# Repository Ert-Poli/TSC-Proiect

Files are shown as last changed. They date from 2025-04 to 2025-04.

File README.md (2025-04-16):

Prezentare Generală

OpenBook ESP32-C6 este o platformă hardware portabilă și eficientă energetic, concepută pentru aplicații embedded. Aceasta are la bază microcontrollerul ESP32-C6-WROOM-1-N8, ce oferă suport pentru Wi-Fi 6 și Bluetooth 5.0 Low Energy, precum și o varietate de interfețe pentru conectarea senzorilor și a altor module externe. Sistemul integrează un ecran e-paper, senzor de mediu BME688, ceas în timp real DS3231SN, memorie NOR Flash de 64MB, cititor pentru card microSD și un sistem de alimentare pe bază de baterie LiPo, cu încărcare integrată și monitorizare a nivelului de energie.

Bill of Materials

Componenta	Link	Datasheet
ESP32_WROVER_EAGLE-LTSPICE_RR0402	https://www.snapeda.com/parts/RC0402FR-07226RL/Yageo/view-part/	https://www.snapeda.com/parts/RC0402FR-07226RL/Yageo/datasheet/
QWIIC_CONNECTORJS-1MM	https://www.snapeda.com/parts/PRT-14417/SparkFun/view-part/	https://www.snapeda.com/parts/PRT-14417/SparkFun%20Electronics/datasheet/
BUTTON_CUSYOMV1	https://industry.panasonic.com/global/en/downloads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	https://industry.panasonic.com/global/en/downloads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
ESP32_WROVER_EAGLE-LTSPICE_CC0402	https://componentsearchengine.com/part-view/CC0402MRX5R5BB106/YAGEO	https://componentsearchengine.com/Datasheets/2/CC0402MRX5R5BB106.pdf
CPH3225A	https://www.snapeda.com/parts/CPH3225A/Seiko+Instruments/view-part/?ref=eda	https://www.snapeda.com/parts/CPH3225A/Seiko%20Instruments/datasheet/
ADAFRUIT_LEDCHIP-LED0603	https://www.snapeda.com/parts/KP-1608SURCK/Kingbright/view-part/?ref=search&t=LED%200603	https://www.snapeda.com/parts/KP-1608SURCK/Kingbright/datasheet/
112A-TAAR-R03_ATTEND	https://store.comet.bg/en/Catalogue/Product/43497/	https://store.comet.bg/en/Catalogue/Product/43497/
744043680IND_4828-WE-TPC_WRE	https://www.digikey.sg/en/models/1638515	https://www.we-online.com/components/products/datasheet/744043680.pdf
BD5229G-TR	https://componentsearchengine.com/part-view/BD5229G-TR/ROHM%20Semiconductor	https://datasheet.datasheetarchive.com/originals/distributors/Datasheets_SAMA/f2b9741ef86007909f138d561a359946.pdf
CPH3225A	https://www.snapeda.com/parts/CPH3225A/Seiko+Instruments/view-part/?ref=eda	https://www.snapeda.com/parts/CPH3225A/Seiko%20Instruments/datasheet/
DS3231SN	https://www.snapeda.com/parts/DS3231SN%23/Analog+Devices/view-part/?ref=eda	https://www.snapeda.com/parts/DS3231SN%23/Analog%20Devices/datasheet/
ESP32-C6-WROOM-1-N8	https://www.snapeda.com/parts/ESP32-C6-WROOM-1-N8/Espressif+Systems/view-part/?ref=eda	https://www.snapeda.com/parts/ESP32-C6-WROOM-1-N8/Espressif%20Systems/datasheet/
MCP73831	https://www.digikey.com/en/models/1874108	https://ww1.microchip.com/downloads/aemDocuments/documents/APID/ProductDocuments/DataSheets/MCP73831-Family-Data-Sheet-DS20001984H.pdf
ESP32_WROVER_BME680_BME680	https://www.snapeda.com/parts/BME680/Bosch/view-part/?welcome=home	https://www.snapeda.com/parts/BME680/Bosch%20Sensortec/datasheet/
ESP32_WROVER_EAGLE-LTSPICE_CC0402	https://componentsearchengine.com/Datasheets/2/CC0402MRX5R5BB106.pdf	https://componentsearchengine.com/part-view/CC0402MRX5R5BB106/YAGEO
ESP32_WROVER_SPARKFUN-DISCRETESEMI_MOSFET_PCH-DMG2305UX-7	https://componentsearchengine.com/part-view/DMG2305UX-7/Diodes%20Incorporated	https://www.diodes.com//assets/Datasheets/DMG2305UX.pdf
ESP32C6_VARISTORCN1812	https://www.mouser.co.uk/ProductDetail/EPCOS-TDK/B72520T0350K062?qs=dEfas%2FXlABIszF52uu7vrg%3D%3D	https://www.tdk-electronics.tdk.com/inf/75/db/CTVS_14/Surge_protection_series.pdf
FH34SRJ-24S-0.5SH_99_	https://componentsearchengine.com/part-view/XC6220A331MR-G/Torex	https://product.torexsemi.com/system/files/series/xc6220.pdf
MAX17048G+T10	https://www.snapeda.com/parts/MAX17048G+T10/Analog+Devices/view-part/?ref=eda	https://www.snapeda.com/parts/MAX17048G+T10/Analog%20Devices/datasheet/
MBR0530	https://ro.mouser.com/ProductDetail/KYOCERA-AVX/SD0805S020S1R0?qs=jCA%252BPfw4LHbpkAoSnwrdjw%3D%3D	https://ro.mouser.com/datasheet/2/40/schottky-3165252.pdf
PGB1010603MR	https://www.snapeda.com/parts/PGB1010603MR/Littelfuse/view-part/?ref=eda	https://www.snapeda.com/parts/PGB1010603MR/Littelfuse%20Inc./datasheet/
RCL_CPOL-EUCT3528	https://ro.mouser.com/ProductDetail/Vishay-Sprague/TR3B106K025C1300?qs=jCGqFXxTmLdffnuDkXzk1g%3D%3D	https://www.vishay.com/docs/40080/tr3.pdf
SAMACSYS_PARTS_USB4110-GF-A	https://componentsearchengine.com/part-view/USB4110-GF-A/GCT%20(GLOBAL%20CONNECTOR%20TECHNOLOGY)	https://gct.co/files/drawings/usb4110.pdf
SI1308EDL-T1-GE3	https://componentsearchengine.com/part-view/SI1308EDL-T1-GE3/Vishay	https://componentsearchengine.com/Datasheets/1/SI1308EDL-T1-GE3.pdf
SJ	https://grabcad.com/library/solder-jumpers-1	
USBLC6-2SC6Y	https://www.snapeda.com/parts/USBLC6-2SC6Y/STMicroelectronics/view-part/?ref=eda	https://www.snapeda.com/parts/USBLC6-2SC6Y/STMicroelectronics/datasheet/
W25Q512JVEIQ	https://www.snapeda.com/parts/W25Q512JVEIQ/Winbond+Electronics/view-part/?ref=eda	https://www.snapeda.com/parts/W25Q512JVEIQ/Winbond%20Electronics/datasheet/
XC6220A331MR-G	https://componentsearchengine.com/part-view/XC6220A331MR-G/Torex



Componente Hardware
ESP32-C6
Microcontrollerul ESP32-C6 gestionează întreaga funcționare a sistemului, inclusiv comunicarea cu perifericele, procesarea datelor și optimizarea consumului energetic.
Arhitectură RISC-V pe 32 de biți
Frecvență: până la 160 MHz
Conectivitate: Wi-Fi 6, Bluetooth 5.0
GPIO-uri versatile pentru interfețe I2C, SPI și UART

Modul RTC – DS3231SN
Ceas în timp real cu precizie ridicată și compensare termică
Funcționează independent de sistem, chiar și în mod oprit
I2C partajat cu senzorul de mediu
Senzor BME688
Măsoară temperatura, umiditatea, presiunea și compuși volatili (VOC)
Conectat pe magistrala I2C comună cu RTC
Ideal pentru analiza condițiilor ambientale și optimizarea afișajului

Ecran E-Paper
Tehnologie de afișaj pasivă, cu consum extrem de redus
Controlat prin SPI și pini RST, DC, BUSY
Dimensiune: 7.5"
Rezoluție: 800x480 px

Memorie NOR Flash – 64MB
Model W25Q512JVEIQ
Stocare SPI pentru loguri și grafice e-paper

Slot microSD
Alternativă de stocare pentru volume mari de date
Comunică prin SPI, cu chip select dedicate

Sistem de Alimentare
Intrare USB-C cu protecție ESD
Suportă baterii LiPo de 3.7V, minim 1500mAh
Încărcător: MCP73831
Monitorizare nivel baterie: MAX17048 (I2C)
Stabilizare tensiune: LDO 3.3V

Protecție și Conectivitate
USB-C cu protecție ESD și diodă Schottky pentru polaritate inversă
Asigură atât alimentare cât și transfer de date

Interfață cu Utilizatorul
Butoane tactile pentru controlul funcțiilor
Conector Qwiic pentru extinderea cu senzori I2C
GPIO-uri disponibile pentru alte extensii

Interfețe de Comunicație
SPI – utilizat pentru e-paper, card SD și memoria NOR Flash
I2C – folosit pentru BME688, DS3231SN și MAX17048
UART – debug și programare
GPIO – pentru control general și butoane
Wireless – conectivitate prin Wi-Fi 6 și BLE 5.0

Supraveghere Tensiune și Reset
Circuit de monitorizare pentru tensiunea de alimentare
Reset automat în caz de instabilitate
Afișare nivel încărcare baterie
Dimensiuni și Design Fizic
Dimensiunea plăcii PCB: aprox. 92 x 54 mm
Design compact, ideal pentru integrarea într-o carcasă personalizată

Specificații Cheie
Consum minim datorită ecranului e-paper și optimizării energetice
Suport extins pentru conectivitate wireless
Măsurători de mediu în timp real
Arhitectură modulară pentru personalizare și extindere facilă
Suport stocare externă pe card microSD

Autonomie ridicată pe baterie
Funcționalitate Software
Compatibilitate cu diverse formate de e-book-uri
Interfață intuitivă pentru citire și navigare
Sincronizare wireless cu dispozitive și servicii externe
Posibilități avansate de personalizare a experienței de utilizare
Logare și analiză a datelor de mediu

Considerații de Design
PCB optimizat pentru reducerea zgomotului electric și creșterea eficienței
Componente cu consum redus alese atent pentru fiabilitate maximă
Sisteme de protecție integrate pentru siguranță
Dimensiuni mici pentru portabilitate crescută

Conectivitate ESP32-C6

Pin ESP32-C6	Funcție	Legat la
IO0	SPI MOSI	E-paper, SD Card, Flash
IO1	SPI MISO	SD Card, Flash
IO2	SPI CLK	Toate dispozitivele SPI
IO3	SPI CS	E-paper
IO4	SPI CS	NOR Flash
IO5	SPI CS	SD Card
IO6	I2C SDA	BME688, RTC, Fuel Gauge
IO7	I2C SCL	BME688, RTC, Fuel Gauge
IO8	Buton Boot	GND prin rezistor
IO10, IO11	UART0	Programare / Debug
EN	Enable MCU	Pull-up la 3.3V

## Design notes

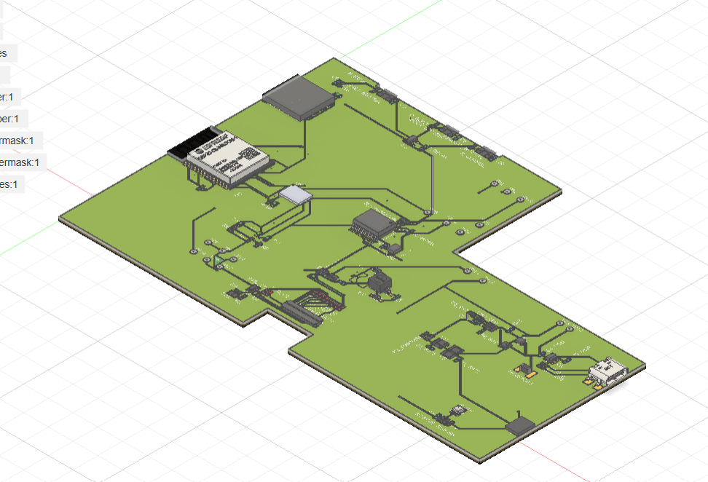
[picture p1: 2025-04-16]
Images/Screenshot .png

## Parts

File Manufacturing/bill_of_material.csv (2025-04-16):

Qty | Value | Device | Package | Parts | Description | ARROW_PART_NUMBER | ARROW_PRICE-STOCK | AVAILABILITY | CENTROID_NOT_SPECIFIED | CHECK_PRICES | COPYRIGHT | DATASHEET | DESCRIPTION | DIGIKEY_DESCRIPTION | DIGIKEY_PART_NUMBER | HEIGHT | LEAD_FREE | MANUFACTURER_NAME | MANUFACTURER_PART_NUMBER | MF | MFR_NAME | MOUSER_PART_NUMBER | MOUSER_PRICE-STOCK | MOUSER_TESTING_PART_NUMBER | MOUSER_TESTING_PRICE-STOCK | MP | MPN | PACKAGE | POPULARITY | PREFIX | PRICE | PROD_ID | PURCHASE-URL | ROHS | SNAPEDA_LINK | SPICEMODEL | SPICEPREFIX | TEMPERATURE_RANGE_HIGH | TEMPERATURE_RANGE_LOW | TP_SIGNAL_NAME | VALUE
1 |  | SJ | SJ | SJ1 | SMD solder JUMPER |  |  |  |  |  |  |  |  |  |  |  |  |  |  |  |  |  |  |  |  |  |  |  | 3
1 | 0.47 | ESP32_WROVER_EAGLE-LTSPICE_RR0402 | ESP32_WROVER_EAGLE-LTSPICE_R0402 | R3 | RESISTOR, European symbol |  |  |  |  |  |  |  |  |  |  |  |  |  |  |  |  |  |  |  |  |  |  |  |  |  |  |  |  |  |  | NONE | R
1 | 100K | ESP32_WROVER_EAGLE-LTSPICE_RR0402 | ESP32_WROVER_EAGLE-LTSPICE_R0402 | R1_PWRUSB | RESISTOR, European symbol |  |  |  |  |  |  |  |  |  |  |  |  |  |  |  |  |  |  |  |  |  |  |  |  |  |  |  |  |  |  | NONE | R
8 | 100nF | EAGLE-LTSPICE_CC0402 | EAGLE-LTSPICE_C0402 | C1, C2, C4_USB, C6, C8, C9, C10, C_DELAY | CAPACITOR, European symbol |  |  |  |  |  |  |  |  |  |  |  |  |  |  |  |  |  |  |  |  |  |  |  |  |  |  |  |  |  |  | NONE | C
1 | 100uF TANT | RCL_CPOL-EUCT3528 | RCL_CT3528 | C3 | POLARIZED CAPACITOR, European symbol |  |  |  |  |  |  |  |  |  |  |  |  |  |  |  |  |  |  |  |  |  |  |  | 0 |  |  |  |  |  |  |  | C
16 | 10K | ESP32_WROVER_EAGLE-LTSPICE_RR0402 | ESP32_WROVER_EAGLE-LTSPICE_R0402 | R1, R1-PINH, R1_PINH1, R2-PINH, R2-PINH1, R4, R5, R6, R7, R8, R9, R10, R_BOOT, R_CHANGE, R_CL1, R_RESET | RESISTOR, European symbol |  |  |  |  |  |  |  |  |  |  |  |  |  |  |  |  |  |  |  |  |  |  |  |  |  |  |  |  |  |  | NONE | R
1 | 10uF | EAGLE-LTSPICE_CC0402 | EAGLE-LTSPICE_C0402 | C7 | CAPACITOR, European symbol |  |  |  |  |  |  |  |  |  |  |  |  |  |  |  |  |  |  |  |  |  |  |  |  |  |  |  |  |  |  | NONE | C
1 | 112A-TAAR-R03_ATTEND | 112A-TAAR-R03_ATTEND | 112ATAARR03ATTEND | J4 | Micro SD Card Socket, Push-Push Type, Top Mount, SMT, H=1.83mm, 10u |  |  |  |  |  |  |  | Micro SD Card Socket | Push-Push Type | Top Mount | SMT | H=1.83mm | 10u |  |  | 1.9mm |  | ATTEND | 112A-TAAR-R03 ATTEND
1 | 15 | ESP32_WROVER_EAGLE-LTSPICE_RR0402 | ESP32_WROVER_EAGLE-LTSPICE_R0402 | R_CAPACITOR | RESISTOR, European symbol |  |  |  |  |  |  |  |  |  |  |  |  |  |  |  |  |  |  |  |  |  |  |  |  |  |  |  |  |  |  | NONE | R
1 | 1uF | EAGLE-LTSPICE_CC0402 | EAGLE-LTSPICE_C0402 | C5 | CAPACITOR, European symbol |  |  |  |  |  |  |  |  |  |  |  |  |  |  |  |  |  |  |  |  |  |  |  |  |  |  |  |  |  |  | NONE | C
10 | 1uF/50V | EAGLE-LTSPICE_CC0402 | EAGLE-LTSPICE_C0402 | EPD_C1, EPD_C2, EPD_C5, EPD_C6, EPD_C7, EPD_C8, EPD_C9, EPD_C10, EPD_C11, EPD_C12 | CAPACITOR, European symbol |  |  |  |  |  |  |  |  |  |  |  |  |  |  |  |  |  |  |  |  |  |  |  |  |  |  |  |  |  |  | NONE | C
1 | 2.2 | ESP32_WROVER_EAGLE-LTSPICE_RR0402 | ESP32_WROVER_EAGLE-LTSPICE_R0402 | R2 | RESISTOR, European symbol |  |  |  |  |  |  |  |  |  |  |  |  |  |  |  |  |  |  |  |  |  |  |  |  |  |  |  |  |  |  | NONE | R
1 | 200 | ESP32_WROVER_EAGLE-LTSPICE_RR0402 | ESP32_WROVER_EAGLE-LTSPICE_R0402 | R1_BAT | RESISTOR, European symbol |  |  |  |  |  |  |  |  |  |  |  |  |  |  |  |  |  |  |  |  |  |  |  |  |  |  |  |  |  |  | NONE | R
2 | 20V/4.2A/52mO/1.4W | ESP32_WROVER_SPARKFUN-DISCRETESEMI_MOSFET_PCH-DMG2305UX-7 | ESP32_WROVER_SPARKFUN-DISCRETESEMI_SOT23-3 | Q1, Q2 | P-channel MOSFETs |  |  |  |  |  |  |  |  |  |  |  |  |  |  |  |  |  |  |  |  |  |  |  |  |  |  | TRAN-14388 |  |  |  |  |  |  |  |  | 20V/4.2A/52mO/1.4W
1 | 2K | ESP32_WROVER_EAGLE-LTSPICE_RR0402 | ESP32_WROVER_EAGLE-LTSPICE_R0402 | R2_BAT | RESISTOR, European symbol |  |  |  |  |  |  |  |  |  |  |  |  |  |  |  |  |  |  |  |  |  |  |  |  |  |  |  |  |  |  | NONE | R
5 | 4.7uF | EAGLE-LTSPICE_CC0402 | EAGLE-LTSPICE_C0402 | C1_BAT, C1_BAT1, C1_BAT2, C2_BAT, C5_USB | CAPACITOR, European symbol |  |  |  |  |  |  |  |  |  |  |  |  |  |  |  |  |  |  |  |  |  |  |  |  |  |  |  |  |  |  | NONE | C
1 | 4.7uF/25V | EAGLE-LTSPICE_CC0402 | EAGLE-LTSPICE_C0402 | C4 | CAPACITOR, European symbol |  |  |  |  |  |  |  |  |  |  |  |  |  |  |  |  |  |  |  |  |  |  |  |  |  |  |  |  |  |  | NONE | C
1 | 5K1 | ESP32_WROVER_EAGLE-LTSPICE_RR0402 | ESP32_WROVER_EAGLE-LTSPICE_R0402 | R2-USB | RESISTOR, European symbol |  |  |  |  |  |  |  |  |  |  |  |  |  |  |  |  |  |  |  |  |  |  |  |  |  |  |  |  |  |  | NONE | R
1 | 5k1 | ESP32_WROVER_EAGLE-LTSPICE_RR0402 | ESP32_WROVER_EAGLE-LTSPICE_R0402 | R2-USB1 | RESISTOR, European symbol |  |  |  |  |  |  |  |  |  |  |  |  |  |  |  |  |  |  |  |  |  |  |  |  |  |  |  |  |  |  | NONE | R
1 | 744043680IND_4828-WE-TPC_WRE | 744043680IND_4828-WE-TPC_WRE | IND_4828-WE-TPC_WRE | L1 |  |  |  |  |  |  | Copyright (C) 2024 Ultra Librarian. All rights reserved. |  |  |  |  |  |  |  | 744043680 |  | Wurth Electronics
1 | BD5229G-TR | BD5229G-TR | SOT95P280X125-5N | IC1 | Voltage Detector with Adjustable Delay Time: CMOS processes are utilized to develop high precision, low current consumption CMOS reset ICs that allow arbitrary setting of the delay time. The extensive lineup includes both Nch Open Drain and CMOS output types in a wide range of detection voltages (from 2.3V to 6.0V, in 0.1V steps), enabling selection of the ideal solution based on customer requirements. In addition, the entire series is of course both lead-free and RoHS-compliant. |  |  |  |  |  |  |  | Voltage Detector with Adjustable Delay Time: CMOS processes are utilized to develop high precision | low current consumption CMOS reset ICs that allow arbitrary setting of the delay time. The extensive lineup includes both Nch Open Drain and CMOS output types in a wide range of detection voltages (from 2.3V to 6.0V | in 0.1V steps) | enabling selection of the ideal solution based on customer requirements. In addition | the entire series is of course both lead-free and RoHS-compliant. |  |  | 1.25mm |  | ROHM Semiconductor | BD5229G-TR |  |  | 755-BD5229G-TR | https://www.mouser.co.uk/ProductDetail/ROHM-Semiconductor/BD5229G-TR?qs=4kLU8WoGk0vvnhrrYwdszw%3D%3D
3 | BUTTON_CUSYOMV1 | BUTTON_CUSYOMV1 | MYBUTTON | BOOT_BUTTON, CHANGE_BUTTON, RESET_BUTTON
1 | CPH3225A | CPH3225A | CAPCP3225X100N | C10_SUPERCAP | Cap 0.011F 3.3V 1210 Flat Check availability |  |  | Not in stock |  | https://www.snapeda.com/parts/CPH3225A/Seiko+Instruments/view-part/?ref=eda |  |  | 11 mF (EDLC) Supercapacitor 3.3 V 1210 (3225 Metric) - - |  |  |  |  |  |  | Seiko Instruments |  |  |  |  |  | CPH3225A |  | 1210 Seiko |  |  | None |  | https://www.snapeda.com/api/url_track_click_mouser/?unipart_id=562593&manufacturer=Seiko Instruments&part_name=CPH3225A&search_term=None |  | https://www.snapeda.com/parts/CPH3225A/Seiko+Instruments/view-part/?ref=snap
1 | DS3231SN# | DS3231SN# | SOIC127P1032X265-16N | U3 | Real Time Clock Serial 16-Pin SOIC W T/R Check availability |  |  | In Stock |  | https://www.snapeda.com/parts/DS3231SN%23/Analog+Devices/view-part/?ref=eda |  |  | Extremely Accurate I²C-Integrated RTC/TCXO/Crystal |  |  |  |  |  |  | Analog Devices |  |  |  |  |  | DS3231SN# |  | SOIC-16 Maxim |  |  | None |  | https://www.snapeda.com/api/url_track_click_mouser/?unipart_id=99048&manufacturer=Analog Devices&part_name=DS3231SN#&search_term=None |  | https://www.snapeda.com/parts/DS3231SN%23/Analog+Devices/view-part/?ref=snap
1 | ESP32-C6-WROOM-1-N8 | ESP32-C6-WROOM-1-N8 | XCVR_ESP32-C6-WROOM-1-N8 | U2 | Check availability |  |  | In Stock |  | https://www.snapeda.com/parts/ESP32-C6-WROOM-1-N8/Espressif+Systems/view-part/?ref=eda |  |  | Multiprotocol Modules ESP32-C6 module | Wi-Fi 6 in 2.4 GHz band | Bluetooth 5 | Zigbee 3.0 and Thread. ESP34-WROOM Compatible - ENGINEERING SAMPLE |  |  |  |  |  |  | Espressif Systems |  |  |  |  |  | ESP32-C6-WROOM-1-N8 |  | None |  |  | None |  |  |  | https://www.snapeda.com/parts/ESP32-C6-WROOM-1-N8/Espressif+Systems/view-part/?ref=snap
1 | ESP32C6_VARISTORCN1812 | ESP32C6_VARISTORCN1812 | ESP32C6_VARISTOR_CT/CN1812 | PFMF.050.1 | VARISTOR |  |  |  |  |  |  |  |  |  |  |  |  |  |  |  |  |  |  |  |  |  |  |  | 0
2 | ESP32_WROVER_AVX---SD0805S020S1R0_AVX_SD0805S020S1R0_0_0AVX_SD0805S020S1R0_0_0 | ESP32_WROVER_AVX---SD0805S020S1R0_AVX_SD0805S020S1R0_0_0AVX_SD0805S020S1R0_0_0 | ESP32_WROVER_AVX---SD0805S020S1R0_AVX_SD0805S020S1R0_0 | D2, D7 | Schottky Barrier Rectifier Diode |  |  |  | No |  |  | http://datasheets.avx.com/schottky.pdf |  | DIODE SCHOTTKY 20V 1A 0805 | 478-7800-1-ND |  | yes |  |  | AVX |  | 581-SD0805S020S1R0 |  |  |  |  |  | 0805 (2012 metric) |  | D |  |  |  | yes |  |  |  | +125°C | -55°C
1 | ESP32_WROVER_BME680_BME680 | ESP32_WROVER_BME680_BME680 | ESP32_WROVER_BME680_PSON80P300X300X100-8N | SENSOR2 | Integrated Environmental Unit |  |  | Unavailable |  |  |  |  | Integrated Environmental Unit |  |  |  |  |  |  | Bosch Sensortec |  |  |  |  |  | BME680 |  | LGA-8 Bosch Tools |  |  | None
1 | ESP32_WROVER_SPARKFUN-IC-POWER_MCP73831 | ESP32_WROVER_SPARKFUN-IC-POWER_MCP73831 | ESP32_WROVER_SPARKFUN-IC-POWER_SOT23-5 | U5 | MCP73831T Li-Ion, Li-Pol Controller |  |  |  |  |  |  |  |  |  |  |  |  |  |  |  |  |  |  |  |  |  |  |  |  |  |  | IC-09995
1 | FH34SRJ-24S-0.5SH_99_ | FH34SRJ-24S-0.5SH_99_ | FH34SRJ24S05SH99 | J1 | (0.50mm) Surface Mount, Right Angle |  |  |  |  |  |  |  | 24 Position FFC | FPC Connector Contacts | (0.50mm) Surface Mount | Right Angle |  |  | 1.1mm |  | Hirose | FH34SRJ-24S-0.5SH(99) |  |  | 798-FH34SRJ24S05SH99 | https://www.mouser.co.uk/ProductDetail/Hirose-Connector/FH34SRJ-24S-0.5SH99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
1 | LG R971 | ADAFRUIT_LEDCHIP-LED0603 | ADAFRUIT_CHIP-LED0603 | CHG_LED | LED
1 | MAX17048G+T10 | MAX17048G+T10 | SON50P200X200X80-9N | U4 | Check availability |  |  | In Stock |  | https://www.snapeda.com/parts/MAX17048G+T10/Analog+Devices/view-part/?ref=eda |  |  | 3µA 1-Cell/2-Cell Fuel Gauge with ModelGauge |  |  |  |  |  |  | Analog Devices |  |  |  |  |  | MAX17048G+T10 |  | TDFN-8 Maxim |  |  | None |  | https://www.snapeda.com/api/url_track_click_mouser/?unipart_id=329239&manufacturer=Analog Devices&part_name=MAX17048G+T10&search_term=None |  | https://www.snapeda.com/parts/MAX17048G+T10/Analog+Devices/view-part/?ref=snap
3 | MBR0530PROBA | MBR0530PROBA | SOD3716X135N | D3, D4, D5 | ON SEMICONDUCTOR - MBR0530 - DIODE, SCHOTTKY, 0.5A, 30V, SOD-123
6 | PGB1010603MRPROBAA | PGB1010603MRPROBAA | DIOC1608X36N | D6, D8, D9, D10, D11, D12 | Check availability
1 | QWIIC_RIGHT_ANGLE | QWIIC_CONNECTORJS-1MM | JST04_1MM_RA | J3 | SparkFun I2C Standard Qwiic Connector |  |  |  |  |  |  |  |  |  |  |  |  |  |  |  |  |  |  |  |  |  |  |  |  |  |  | CONN-13694 |  |  |  |  |  |  |  |  | QWIIC_RIGHT_ANGLE
1 | SAMACSYS_PARTS_USB4110-GF-A | SAMACSYS_PARTS_USB4110-GF-A | SAMACSYS_PARTS_USB4110GFA | J2 | CONN USB 2.0 TYPE-C R/A SMT |  |  |  |  |  |  |  | CONN USB 2.0 TYPE-C R/A SMT |  |  | 3.26mm |  | GCT (GLOBAL CONNECTOR TECHNOLOGY) | USB4110-GF-A |  |  | 640-USB4110-GF-A | https://www.mouser.co.uk/ProductDetail/GCT/USB4110-GF-A?qs=KUoIvG%2F9IlYiZvIXQjyJeA%3D%3D
1 | SI1308EDL-T1-GE3 | SI1308EDL-T1-GE3 | SOT65P210X110-3N | Q3 | MOSFET N-Ch 30V 1.5A TrenchFET SC70 Vishay Si1308EDL-T1-GE3 N-channel MOSFET Transistor, 1.5 A, 30 V, 3-Pin SC-70 |  |  | In Stock |  | https://www.snapeda.com/parts/SI1308EDL-T1-GE3/Vishay+Siliconix/view-part/?ref=eda |  |  | Si1308EDL-T1-GE3 N-channel MOSFET Transistor | 1.5 A | 30 V | 3-Pin SC-70 | Siliconix / Vishay SI1308EDL-T1-GE3 |  |  |  |  |  |  | Vishay Siliconix |  |  |  |  |  | SI1308EDL-T1-GE3 |  | SOT-323 Vishay Semiconductor |  |  | None |  | https://www.snapeda.com/api/url_track_click_mouser/?unipart_id=274603&manufacturer=Vishay Siliconix&part_name=SI1308EDL-T1-GE3&search_term=None |  | https://www.snapeda.com/parts/SI1308EDL-T1-GE3/Vishay+Siliconix/view-part/?ref=snap
17 | TPTP20R | TPTP20R | TP20R | TP1, TP2, TP3, TP4, TP5, TP6, TP7, TP8, TP9, TP10, TP11, TP12, TP13, TP14, TP15, TP16, TP17 | Test pad |  |  |  |  |  |  |  |  |  |  |  |  |  |  |  |  |  |  |  |  |  |  |  | 2
1 | USBLC6-2SC6Y | USBLC6-2SC6Y | SOT95P280X145-6N | D1 | Low Cap. ESD Protection Auto SOT-23-6 STMicroelectronics USBLC6-2SC6Y, Dual Uni-Directional TVS Diode Array, 6-Pin SOT-23 |  |  | In Stock |  | https://www.snapeda.com/parts/USBLC6-2SC6Y/STMicroelectronics/view-part/?ref=eda |  |  | 17V Clamp 5A (8/20µs) Ipp Tvs Diode Surface Mount SOT-23-6 |  |  |  |  |  |  | STMicroelectronics |  |  |  |  |  | USBLC6-2SC6Y |  | SOT-23-6 STMicroelectronics |  |  | None |  |  |  | https://www.snapeda.com/parts/USBLC6-2SC6Y/STMicroelectronics/view-part/?ref=snap
1 | W25Q512JVEIQ | W25Q512JVEIQ | SON127P600X800X80-9N | U1 | Check availability |  |  | In Stock |  | https://www.snapeda.com/parts/W25Q512JVEIQ/Winbond+Electronics/view-part/?ref=eda |  |  | FLASH - NOR Memory IC 512Mb (64M x 8) SPI - Quad I/O 133 MHz 8-WSON (8x6) |  |  |  |  |  |  | Winbond Electronics |  |  |  |  |  | W25Q512JVEIQ |  | Package |  |  | None |  |  |  | https://www.snapeda.com/parts/W25Q512JVEIQ/Winbond+Electronics/view-part/?ref=snap
1 | XC6220A331MR-G | XC6220A331MR-G | SOT95P280X120-5N | IC4 | LDO Voltage Regulators |  |  |  |  |  |  |  | LDO Voltage Regulators |  |  | 1.2mm |  | Torex | XC6220A331MR-G |  |  | 865-XC6220A331MR-G | https://www.mouser.co.uk/ProductDetail/Torex-Semiconductor/XC6220A331MR-G?qs=AsjdqWjXhJ8ZSWznL1J0gg%3D%3D

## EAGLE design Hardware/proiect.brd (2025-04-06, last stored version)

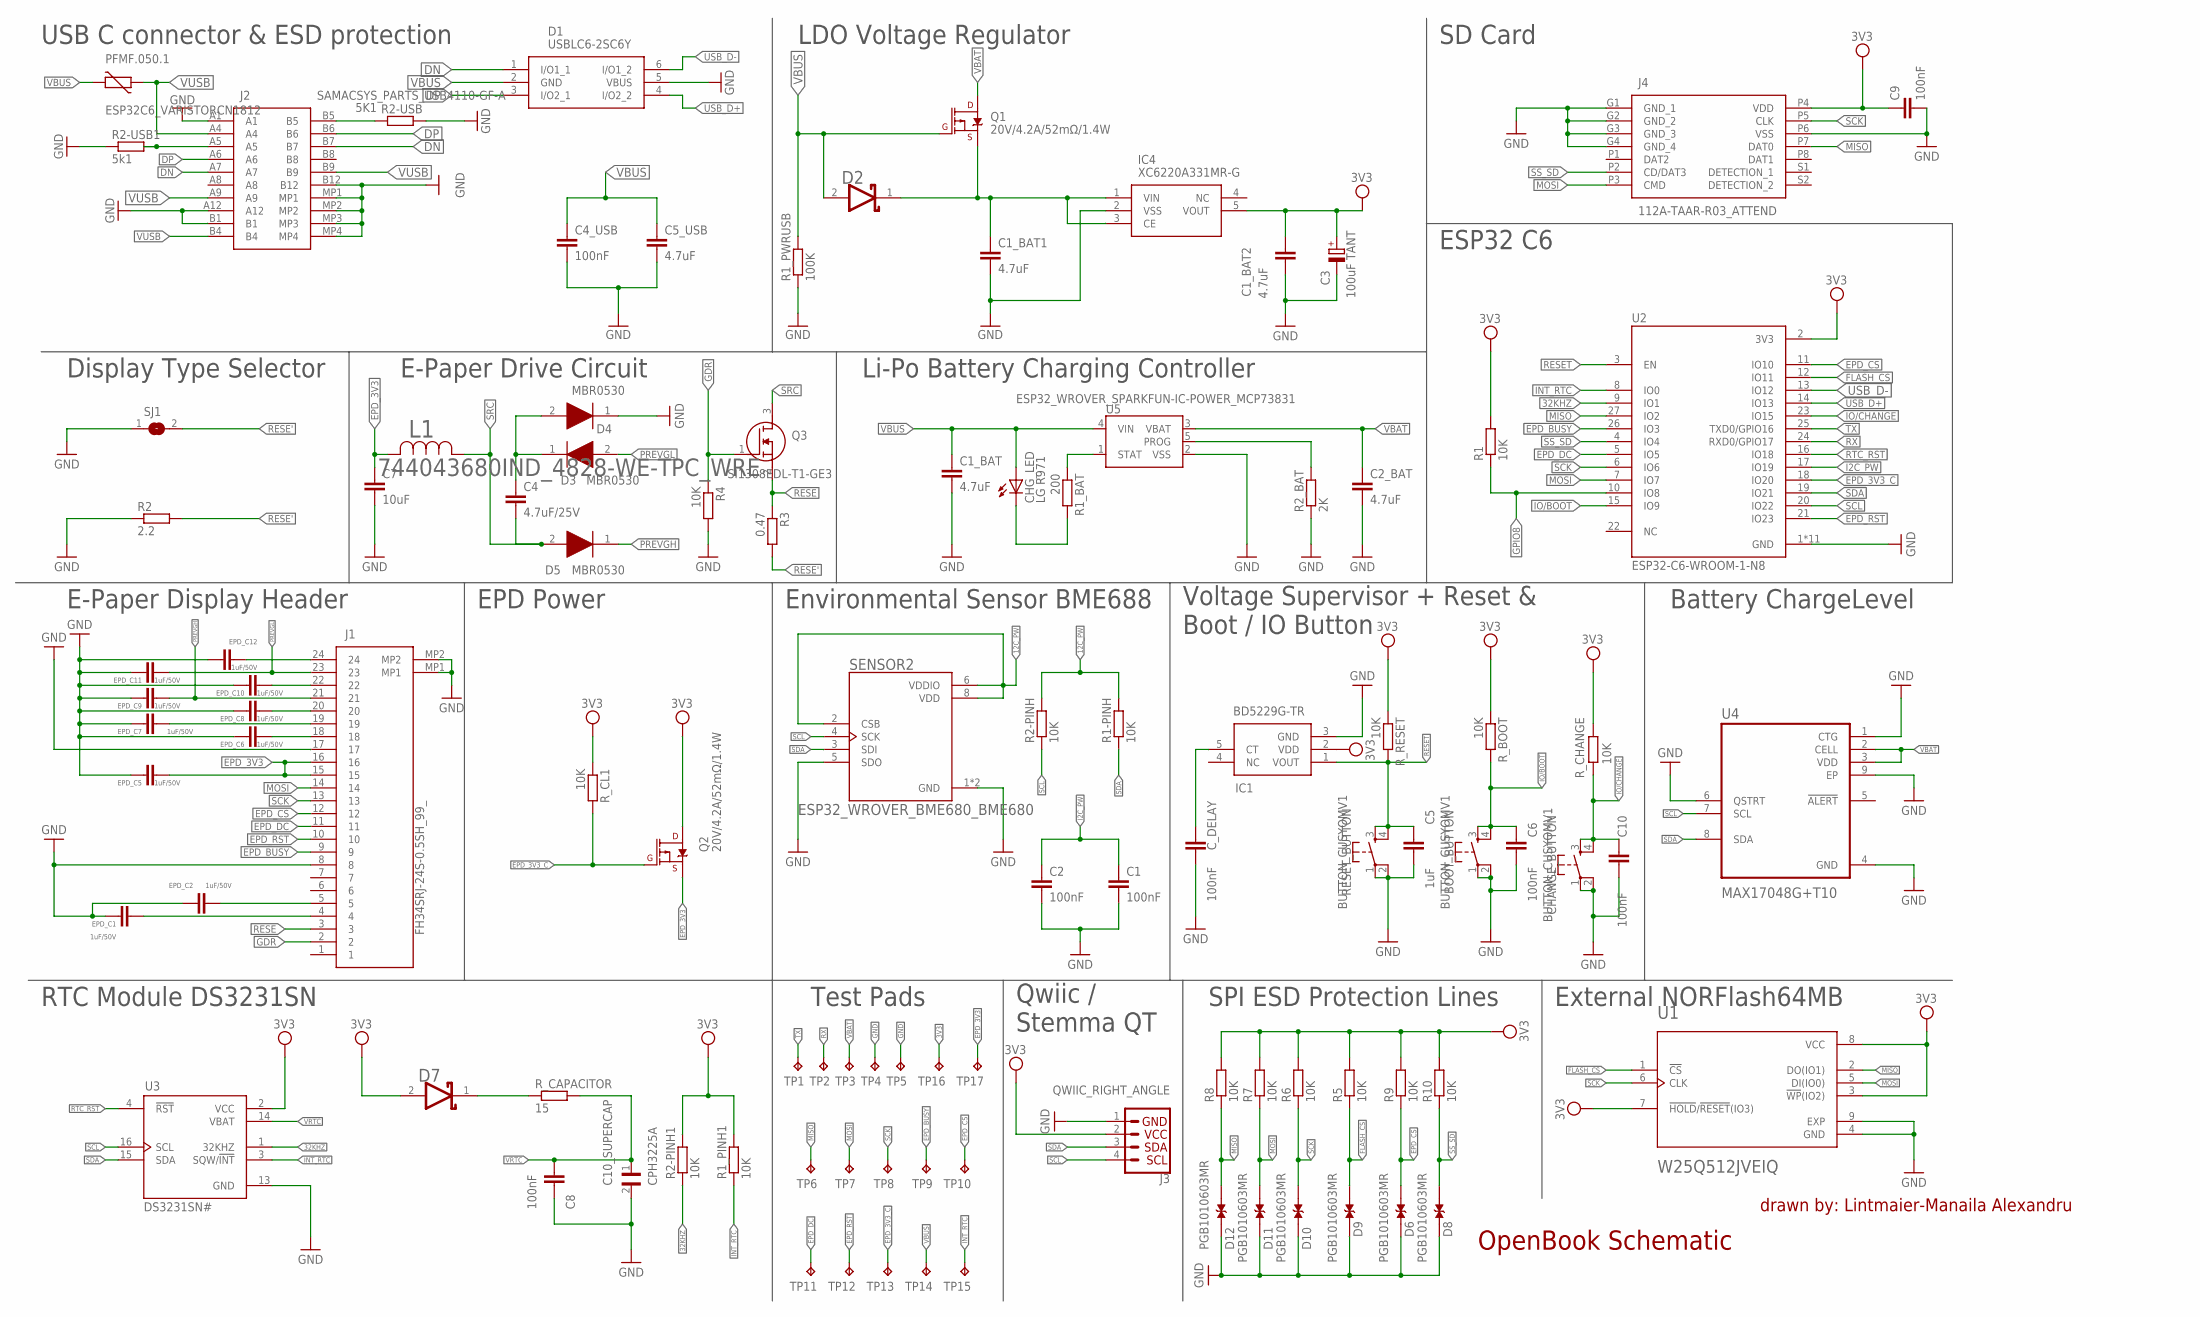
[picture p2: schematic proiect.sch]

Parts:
BOOT_BUTTON: BUTTON_CUSYOMV1; MYBUTTON
C1, C2, C4_USB, C6, C8, C9, C10: 100nF; EAGLE-LTSPICE_C0402
C1_BAT, C1_BAT1, C1_BAT2, C2_BAT, C5_USB: 4.7uF; EAGLE-LTSPICE_C0402
C3: 100uF TANT; RCL_CT3528
C4: 4.7uF/25V; EAGLE-LTSPICE_C0402
C5: 1uF; EAGLE-LTSPICE_C0402
C7: 10uF; EAGLE-LTSPICE_C0402
C10_SUPERCAP: CPH3225A; CAPCP3225X100N
CHANGE_BUTTON: BUTTON_CUSYOMV1; MYBUTTON
CHG_LED: LG R971; ADAFRUIT_CHIP-LED0603
C_DELAY: 100nF; EAGLE-LTSPICE_C0402
D1: USBLC6-2SC6Y; SOT95P280X145-6N
D2, D7: ESP32_WROVER_AVX---SD0805S020S1R0_AVX_SD0805S020S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; ESP32_WROVER_AVX---SD0805S020S1R0_AVX_SD0805S020S1R0_0
D3, D4, D5: MBR0530; SOD3716X135N
D6, D8, D9, D10, D11, D12: PGB1010603MR; DIOC1608X36N
EPD_C1, EPD_C2, EPD_C5, EPD_C6, EPD_C7, EPD_C8, EPD_C9, EPD_C10, EPD_C11, EPD_C12: 1uF/50V; EAGLE-LTSPICE_C0402
IC1: BD5229G-TR; SOT95P280X125-5N
IC4: XC6220A331MR-G; SOT95P280X120-5N
J1: FH34SRJ-24S-0.5SH_99_; FH34SRJ24S05SH99
J2: SAMACSYS_PARTS_USB4110-GF-A; SAMACSYS_PARTS_USB4110GFA
J3: QWIIC_RIGHT_ANGLE; JST04_1MM_RA
J4: 112A-TAAR-R03_ATTEND; 112ATAARR03ATTEND
L1: 744043680IND_4828-WE-TPC_WRE; IND_4828-WE-TPC_WRE
PFMF.050.1: ESP32C6_VARISTORCN1812; ESP32C6_VARISTOR_CT/CN1812
Q1, Q2: 20V/4.2A/52mΩ/1.4W; ESP32_WROVER_SPARKFUN-DISCRETESEMI_SOT23-3
Q3: SI1308EDL-T1-GE3; SOT65P210X110-3N
R1, R1-PINH, R1_PINH1, R2-PINH, R2-PINH1, R4, R5, R6, R7, R8, R9, R10: 10K; ESP32_WROVER_EAGLE-LTSPICE_R0402
R1_BAT: 200; ESP32_WROVER_EAGLE-LTSPICE_R0402
R1_PWRUSB: 100K; ESP32_WROVER_EAGLE-LTSPICE_R0402
R2: 2.2; ESP32_WROVER_EAGLE-LTSPICE_R0402
R2-USB: 5K1; ESP32_WROVER_EAGLE-LTSPICE_R0402
R2-USB1: 5k1; ESP32_WROVER_EAGLE-LTSPICE_R0402
R2_BAT: 2K; ESP32_WROVER_EAGLE-LTSPICE_R0402
R3: 0.47; ESP32_WROVER_EAGLE-LTSPICE_R0402
RESET_BUTTON: BUTTON_CUSYOMV1; MYBUTTON
R_BOOT: 10K; ESP32_WROVER_EAGLE-LTSPICE_R0402
R_CAPACITOR: 15; ESP32_WROVER_EAGLE-LTSPICE_R0402
R_CHANGE: 10K; ESP32_WROVER_EAGLE-LTSPICE_R0402
R_CL1: 10K; ESP32_WROVER_EAGLE-LTSPICE_R0402
R_RESET: 10K; ESP32_WROVER_EAGLE-LTSPICE_R0402
SENSOR2: ESP32_WROVER_BME680_BME680; ESP32_WROVER_BME680_PSON80P300X300X100-8N
SJ1: SJ
TP1, TP2, TP3, TP4, TP5, TP6, TP7, TP8, TP9, TP10, TP11, TP12, TP13, TP14, TP15, TP16, TP17: TPTP20R; TP20R
U1: W25Q512JVEIQ; SON127P600X800X80-9N
U2: ESP32-C6-WROOM-1-N8; XCVR_ESP32-C6-WROOM-1-N8
U3: DS3231SN#; SOIC127P1032X265-16N
U4: MAX17048G+T10; SON50P200X200X80-9N
U5: ESP32_WROVER_SPARKFUN-IC-POWER_MCP73831; ESP32_WROVER_SPARKFUN-IC-POWER_SOT23-5

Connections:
3V3: C1_BAT2.1, C3.+, C9.1, D7.2 (ANODE), IC1.2 (VDD), IC4.5 (VOUT), J3.2, J4.P4 (VDD), Q2.3 (D), R1.2, R1_PINH1.2, R2-PINH1.2, R5.2, R6.2, R7.2, R8.2, R9.2, R10.2, R_BOOT.1, R_CHANGE.1, R_CL1.1, R_RESET.1, TP16.TP, U1.3 (!WP!(IO2)), U1.7 (!HOLD!/!RESET!(IO3)), U1.8 (VCC), U2.2 (3V3), U3.2 (VCC)
12C_PW: R1-PINH.2, R2-PINH.2, SENSOR2.2 (CSB), SENSOR2.6 (VDDIO), SENSOR2.8 (VDD)
32KHZ: R2-PINH1.1, U2.9 (IO1), U3.1 (32KHZ)
DN: D1.1 (I/O1_1), J2.A7, J2.B7
DP: D1.3 (I/O2_1), J2.A6, J2.B6
EPD_3V3: C7.1, EPD_C5.2, J1.15, J1.16, L1.2, Q2.2 (S), TP17.TP
EPD_3V3_C: Q2.1 (G), R_CL1.2, TP13.TP, U2.18 (IO20)
EPD_BUSY: J1.9, TP9.TP, U2.26 (IO3)
EPD_CS: D6.2, J1.12, R9.1, TP10.TP, U2.11 (IO10)
EPD_DC: J1.11, TP11.TP, U2.5 (IO5)
EPD_RST: J1.10, TP12.TP, U2.21 (IO23)
FLASH_CS: D9.2, R5.1, U1.1 (!CS), U2.12 (IO11)
GDR: J1.2, Q3.1 (G), R4.1
GND: BOOT_BUTTON.1, BOOT_BUTTON.2, C1.2, C1_BAT.2, C1_BAT1.2, C1_BAT2.2, C2.2, C2_BAT.2, C3.-, C4_USB.2, C5.2, C5_USB.2, C6.2, C7.2, C8.2, C9.2, C10.2, C10_SUPERCAP.2, CHANGE_BUTTON.1, CHANGE_BUTTON.2, C_DELAY.2, D1.5 (VBUS), D4.1 (K), D6.1, D8.1, D9.1, D10.1, D11.1, D12.1, EPD_C1.1, EPD_C2.1, EPD_C5.1, EPD_C6.1, EPD_C7.1, EPD_C8.1, EPD_C9.1, EPD_C10.1, EPD_C11.1, EPD_C12.1, IC1.3 (GND), IC4.2 (VSS), J1.8, J1.17, J1.MP1, J1.MP2, J2.A1, J2.A12, J2.B1, J2.B12, J2.MP1, J2.MP2, J2.MP3, J2.MP4, J3.1, J4.G1 (GND_1), J4.G2 (GND_2), J4.G3 (GND_3), J4.G4 (GND_4), J4.P6 (VSS), R1_PWRUSB.1, R2.1, R2-USB.2, R2-USB1.1, R2_BAT.1, R4.2, RESET_BUTTON.1, RESET_BUTTON.2, SENSOR2.1 (GND), SENSOR2.5 (SDO), SENSOR2.7 (GND), SJ1.1, TP4.TP, TP5.TP, U1.4 (GND), U1.9 (EXP), U2.1 (GND), U2.28 (GND), U2.29_1 (GND), U2.29_2 (GND), U2.29_3 (GND), U2.29_4 (GND), U2.29_5 (GND), U2.29_6 (GND), U2.29_7 (GND), U2.29_8 (GND), U2.29_9 (GND), U3.13 (GND), U4.1 (CTG), U4.4 (GND), U4.6 (QSTRT), U4.9 (EP), U5.2 (VSS)
GPIO8: R1.1, U2.10 (IO8)
I2C_PW: C1.1, C2.1, U2.17 (IO19)
INT_RTC: R1_PINH1.1, TP15.TP, U2.8 (IO0), U3.3 (SQW/!INT)
IO/BOOT: BOOT_BUTTON.3, BOOT_BUTTON.4, C6.1, R_BOOT.2, U2.15 (IO9)
IO/CHANGE: C10.1, CHANGE_BUTTON.3, CHANGE_BUTTON.4, R_CHANGE.2, U2.23 (IO15)
MISO: D12.2, J4.P7 (DAT0), R8.1, TP6.TP, U1.2 (DO(IO1)), U2.27 (IO2)
MOSI: D11.2, J1.14, J4.P3 (CMD), R7.1, TP7.TP, U1.5 (DI(IO0)), U2.7 (IO7)
unnamed: J2.A5, R2-USB1.2
unnamed: J2.B5, R2-USB.1
unnamed: C1_BAT1.1, D2.1 (CATHODE), IC4.1 (VIN), IC4.3 (CE), Q1.2 (S)
unnamed: CHG_LED.C, R1_BAT.2
unnamed: R1_BAT.1, U5.1 (STAT)
unnamed: EPD_C1.2, J1.4
unnamed: R2_BAT.2, U5.5 (PROG)
unnamed: C4.1, D3.1 (K), D4.2 (A)
unnamed: EPD_C2.2, J1.5
unnamed: EPD_C6.2, J1.18
unnamed: EPD_C7.2, J1.19
unnamed: EPD_C8.2, J1.20
unnamed: C_DELAY.1, IC1.5 (CT)
unnamed: EPD_C10.2, J1.22
unnamed: EPD_C12.2, J1.24
unnamed: D7.1 (CATHODE), R_CAPACITOR.1
PREVGH: D5.1 (K), EPD_C9.2, J1.21
PREVGL: D3.2 (A), EPD_C11.2, J1.23
RESE: J1.3, Q3.2 (S), R3.1
RESE': R2.2, R3.2, SJ1.2
RESET: C5.1, IC1.1 (VOUT), RESET_BUTTON.3, RESET_BUTTON.4, R_RESET.2, U2.3 (EN)
RTC_RST: U2.16 (IO18), U3.4 (!RST)
RX: TP2.TP, U2.24 (RXD0/GPIO17)
SCK: D10.2, J1.13, J4.P5 (CLK), R6.1, TP8.TP, U1.6 (CLK), U2.6 (IO6)
SCL: J3.4, R2-PINH.1, SENSOR2.4 (SCK), U2.20 (IO22), U3.16 (SCL), U4.7 (SCL)
SDA: J3.3, R1-PINH.1, SENSOR2.3 (SDI), U2.19 (IO21), U3.15 (SDA), U4.8 (SDA)
SRC: C4.2, D5.2 (A), L1.1, Q3.3 (D)
SS_SD: D8.2, J4.P2 (CD/DAT3), R10.1, U2.4 (IO4)
TX: TP1.TP, U2.25 (TXD0/GPIO16)
USB_D+: D1.4 (I/O2_2), U2.14 (IO13)
USB_D-: D1.6 (I/O1_2), U2.13 (IO12)
VBAT: C2_BAT.1, Q1.3 (D), TP3.TP, U4.2 (CELL), U4.3 (VDD), U5.3 (VBAT)
VBUS: C1_BAT.1, C4_USB.1, C5_USB.1, CHG_LED.A, D1.2 (GND), D2.2 (ANODE), PFMF.050.1.2, Q1.1 (G), R1_PWRUSB.2, TP14.TP, U5.4 (VIN)
VRTC: C8.1, C10_SUPERCAP.1, R_CAPACITOR.2, U3.14 (VBAT)
VUSB: J2.A4, J2.A9, J2.B4, J2.B9, PFMF.050.1.1

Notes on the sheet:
USB C connector & ESD protection
LDO Voltage Regulator
SD Card
ESP32 C6
Li-Po Battery Charging Controller
E-Paper Drive Circuit
Display Type Selector
E-Paper Display Header
EPD Power
Environmental Sensor BME688
Voltage Supervisor + Reset & Boot / IO Button
Battery ChargeLevel
RTC Module DS3231SN
Test Pads
Qwiic / Stemma QT
SPI ESD Protection Lines
External NORFlash64MB
OpenBook Schematic
drawn by: Lintmaier-Manaila Alexandru

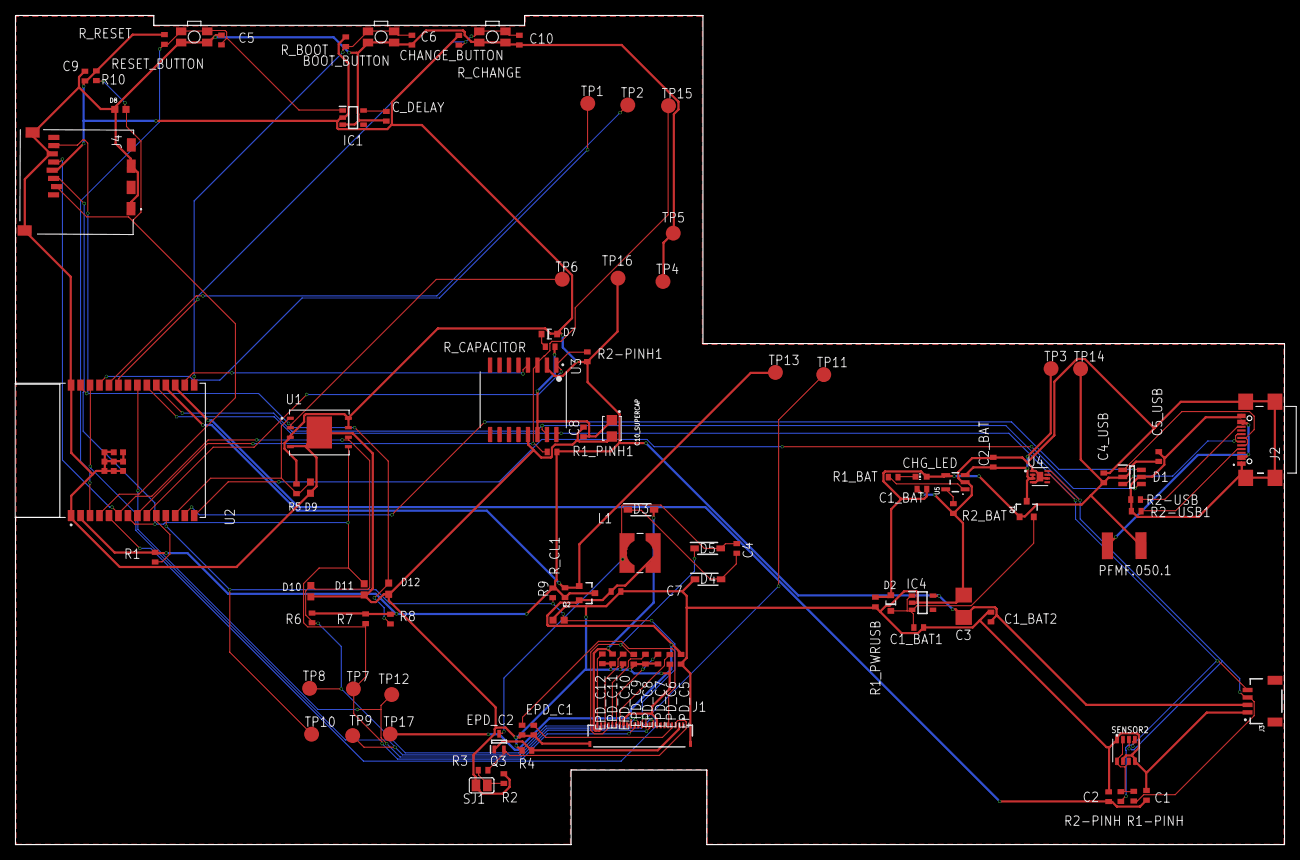
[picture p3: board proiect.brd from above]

Board: 2 copper layers, 170.2 x 111.2 mm, 103 parts (0 on the bottom side), 56 nets.

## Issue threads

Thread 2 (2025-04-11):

[PCB] - Copper width eroare

WhyNotZebra, 2025-04-11:
Piesa L1 are eroare de copper width
Poti sa le rezolvi cu edit footprint si sa schimbi dimensiunea, pad-urile au o lățime mai mică decât cea permisă de regulile de proiectare (DRC)

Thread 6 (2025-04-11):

[3D Models] - Lipsesc 3d Models

WhyNotZebra, 2025-04-11:
Nu există modele 3D atașate componentelor. Nu există un model 3D pentru placa PCB sau pentru dispozitivul complet (inclusiv o baterie și un ecran).
Ia în considerare realizarea unui model 3D pentru dispozitiv.
Resurse utile:
https://componentsearchengine.com
https://www.snapeda.com
https://grabcad.com/library

Closed 2025-04-16.

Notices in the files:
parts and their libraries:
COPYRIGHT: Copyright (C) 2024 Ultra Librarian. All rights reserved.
